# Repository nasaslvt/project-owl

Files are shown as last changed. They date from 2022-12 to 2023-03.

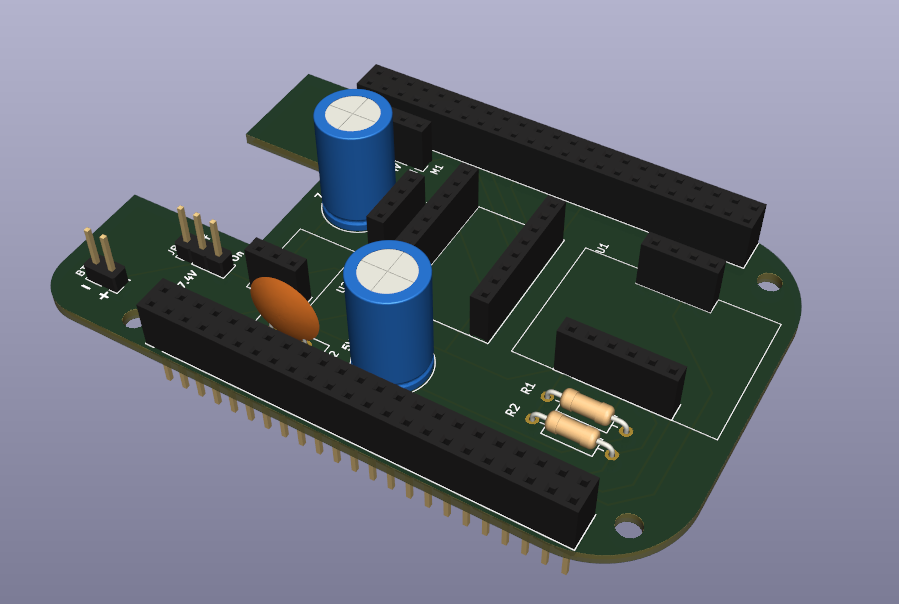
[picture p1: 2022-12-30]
doc/cape_model_v1-4.png

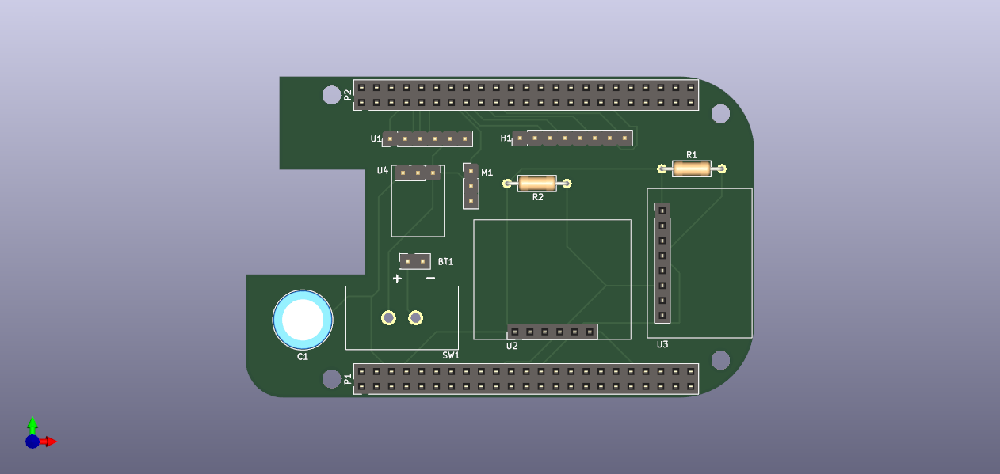
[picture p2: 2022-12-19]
kicad/cape/cape.png

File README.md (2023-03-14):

# project-owl

## Repository Structure
- `beagle`: BeagleBone Black source code
- `conf`: Configuration files, especially for Dire Wolf
- `doc`: Documentation, including block diagrams and schematics
- `esp`: ESP32-CAM source code
- `kicad`: KiCad project files

## Documentation

Schematics were created with KiCad and follow the \<version>.\<subversion> naming convention.  
Block diagrams were created with DigiKey's online [SchemeIt tool](https://www.digikey.com/schemeit/project/project-owl-26cf1e4f4a01456586e33678977ee045).

## Configuration

#### Setup

Install rtl_test, rtl_fm, etc.
```bash
apt-get install rtl-sdr sox
```

Build and install the latest direwolf (1.6 at time of this writing)
```bash
sudo apt-get install git gcc g++ make cmake libasound2-dev libudev-dev
cd ~
mkdir src && cd src
git clone https://www.github.com/wb2osz/direwolf
mkdir build && cd build
cmake ..
make -j4
sudo make install
make install-conf
exit
```

Copy `receive.conf` from this repository to `~/conf/receive.conf`

### ESP32-Camera

#### Flashing

todo

## Operation
### Using rtl_fm
[Reference guide](http://kmkeen.com/rtl-demod-guide/).
To listen to FM radio: `rtl_fm -M wbfm -f 90.7M | sox -r 32k -t raw -e s -b 16 -c 1 -V1 - test.wav`
To use rtl_fm and Dire Wolf: `rtl_fm  -f 145.70M - | direwolf -c receive.conf` or run `receive.sh`.
We are using **145.70 MHz** as our test frequency, although APRS for North America is 144.39M. 

## Debugging
The user running Dire Wolf must be a member of the `audio` group.

## Licensing
The KiCad footprint and model for the L101011MS02Q were provided by SnapEDA under the CC-BY-SA 4.0 license: https://www.snapeda.com/parts/L101011MS02Q/C&K/view-part/?ref=digikey

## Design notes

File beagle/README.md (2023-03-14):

# BeagleBone Black Wireless

The BeagleBone Black Wireless (BBB) is running the [Debian 10.3 2020-04-06 4GB eMMC IoT firmware](https://debian.beagleboard.org/images/bone-eMMC-flasher-debian-10.3-iot-armhf-2020-04-06-4gb.img.xz). This firmware is a Debian Buster IoT (without graphical desktop) image specifically designed for flashing the on-board eMMC memory of the BeagleBone via a microSD card.

The BBB is hosting a wireless access point with the SSID "owl". The network has a DHCP range of 192.168.8.50 to 192.168.8.150 and a listen address of 192.168.8.1. The ESP32-Cam is configured to connect to this network on startup with a static ip address of 192.168.8.10.

## Configuration

#### Flashing Firmware

* Use the Rufus software to flash the [Debian 10.3 2020-04-06 4GB eMMC IoT Flasher image](https://debian.beagleboard.org/images/bone-eMMC-flasher-debian-10.3-iot-armhf-2020-04-06-4gb.img.xz) onto the SD card. 
* Insert the SD card into the BeagleBone and hold down the "User Boot" button (located near the SD card slot). 
* Connect the power source (USB or 5V adaptor) while holding down the "User Boot" button.
* Release the button once the bank of 4 LED's light up for a few seconds.
* The flashing process will take approximately 30-45 minutes. 
* Once the flashing is complete, the bank of 4 LED's to the right of the Ethernet will turn off. 
* Power down the BeagleBone Black, remove the SD card, and power up the BeagleBone Black. 

* To connect to the BeagleBone via USB, use the following command:
```bash
ssh debian@192.168.7.1 or ssh debian@192.168.6.1
```
* When prompted, enter the password `temppwd`.

* Configure users and passwords
```bash
sudo su
passwd
adduser slvt
usermod -aG sudo slvt
```

* Setup Wireless Access Point
```bash
sudo sed -i -e 's:USE_PERSONAL_SSID="BeagleBone":USE_PERSONAL_SSID="owl":g' /etc/default/bb-wl18xx
sudo sed -i -e 's:USE_PERSONAL_PASSWORD="BeagleBone":USE_PERSONAL_PASSWORD="str1g1f0rm35":g' /etc/default/bb-wl18xx
sudo sed -i -e 's:USE_APPENDED_SSID=yes:USE_APPENDED_SSID=no:g' /etc/default/bb-wl18xx
sudo reboot now
```

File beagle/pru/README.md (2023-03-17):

# Programmable Real-Time Unit

## Overview

The BeagleBone has both an ARM processor running Linux and two Programmable Real-Time Units (PRUs). The PRUs have 32-bit cores which run independently of the ARM processor, therefore they can be programmed to respond quickly to inputs and produce very precisely timed outputs. This is necessary for our application, which requires the use of two Parallax Feedback 360° High-Speed Servos. These servos are controlled by a 50 Hz PWM signal, and also have a return signal line from an internal Hall effect sensor system that provides digital angular position feedback at a frequency of 910 Hz. To decode this signal in software, the PRU is used to handle the return signal, reading the data and sending it back to the ARM processor. The ARM processor then uses this data to control the servo, with each PRU reading the feedback signal of an individual servo.

## Configuration

In order to enable the swivel servo feedback pin (P8_15) and rotation servo feedback pin (P8_27) to work with the PRU, the pins must be explicitly configured. To configure P8_15, the command `config-pin P8_15 pruin` must be used. To configure P8_27, the virtual cape for HDMI functionality must first be disabled by uncommenting the `disable_uboot_overlay_video=1` line in `/boot/uEnv.txt` and rebooting. Then the command `config-pin P8_27 pruin` can be used to configure the pin.

## Usage

```
sudo ./start.sh
```

## References
1. [PRU Cookbook](https://beagleboard.org/static/prucookbook/)
2. [Frequency Measurement with PRU BeagleBone CYCLE Register](https://github.com/SuperEjik/frequency-measurement-with-PRU-BeagleBone-CYCLE-register-)
3. [Programming the BeagleBone PRU-ICSS](https://www.glennklockwood.com/embedded/beaglebone-pru.html)
4. [AM335x and AMIC110 Sitara™ Processors Technical Reference Manual](https://www.ti.com/lit/ug/spruh73q/spruh73q.pdf)
5. [BeagleBone Black System Reference Manual 2020](https://kilobaser.com/wp-content/uploads/2021/02/BBB_SRM.pdf)
6. [PRU Debugger](https://github.com/poopgiggle/prudebug)

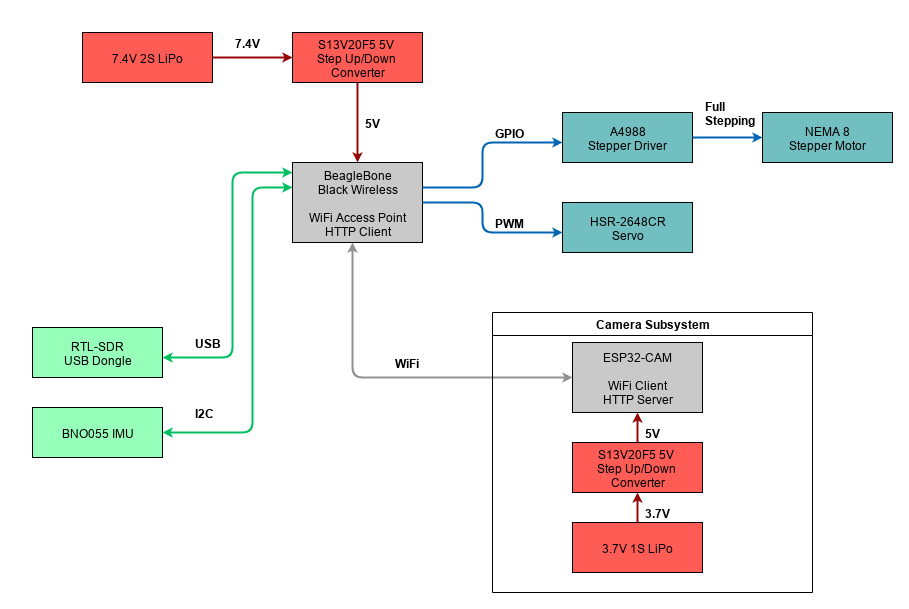
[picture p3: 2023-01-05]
doc/Project-OWL.png

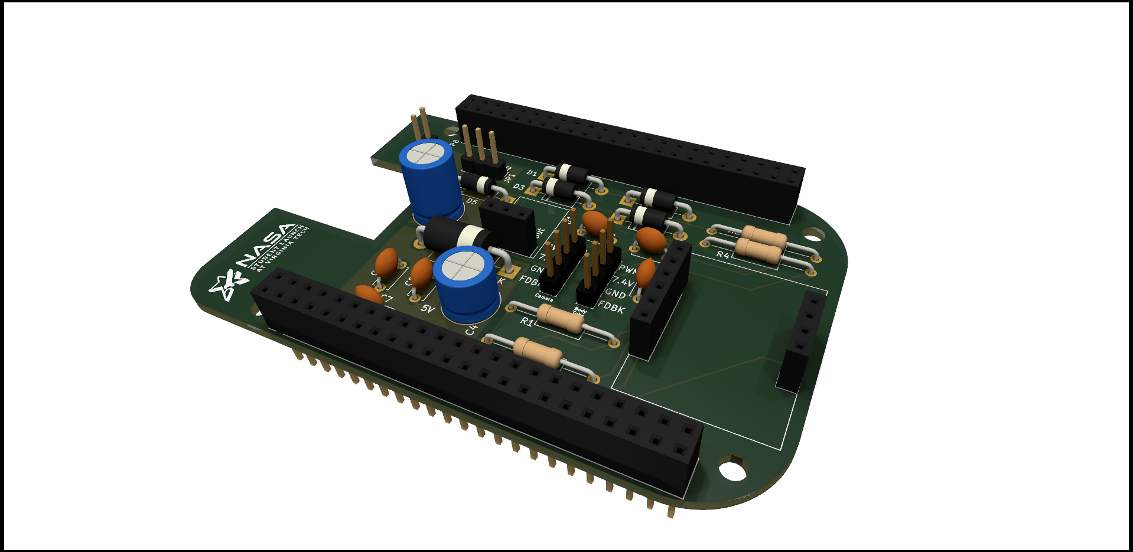
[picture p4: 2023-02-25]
kicad/cape/cape_orthographic.png

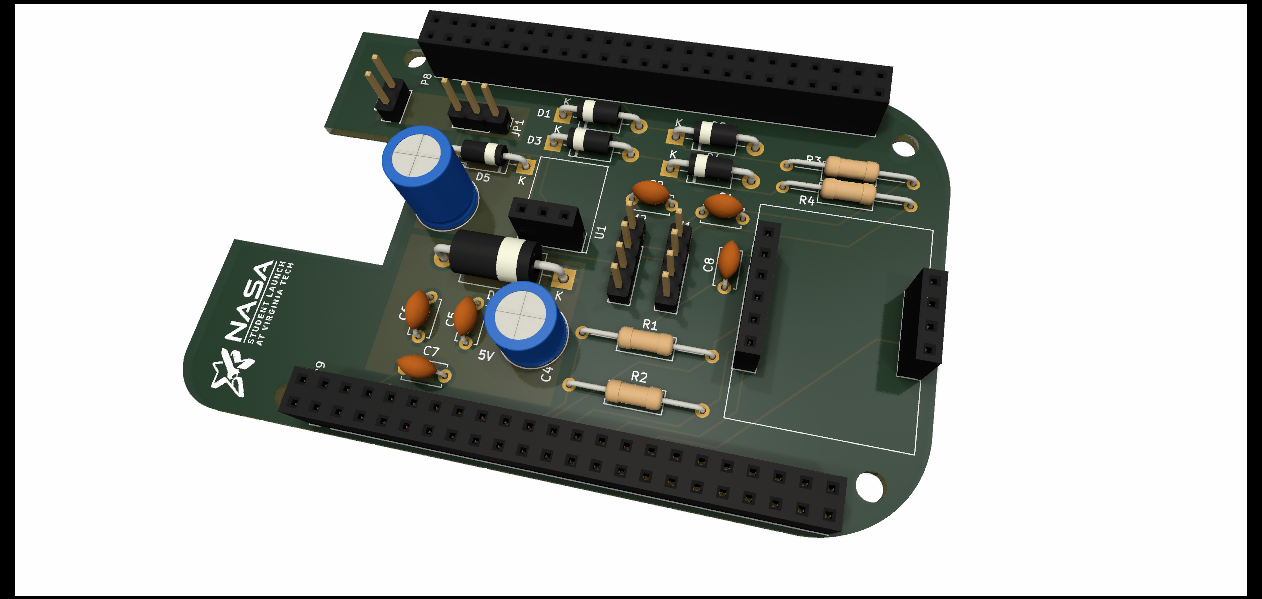
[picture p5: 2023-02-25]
kicad/cape/cape_raytraced.png

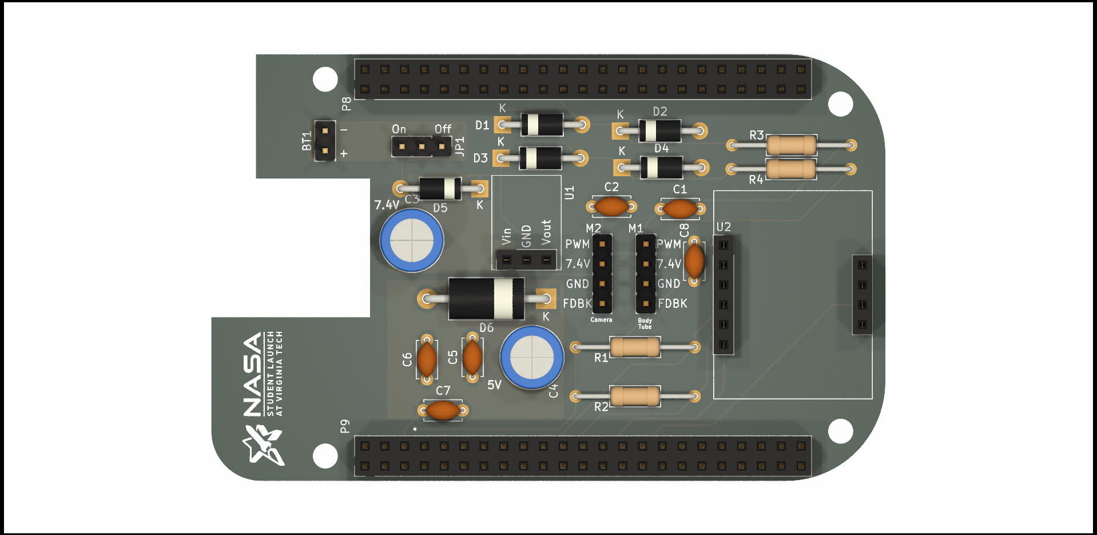
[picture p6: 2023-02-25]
kicad/cape/cape_isometric.png

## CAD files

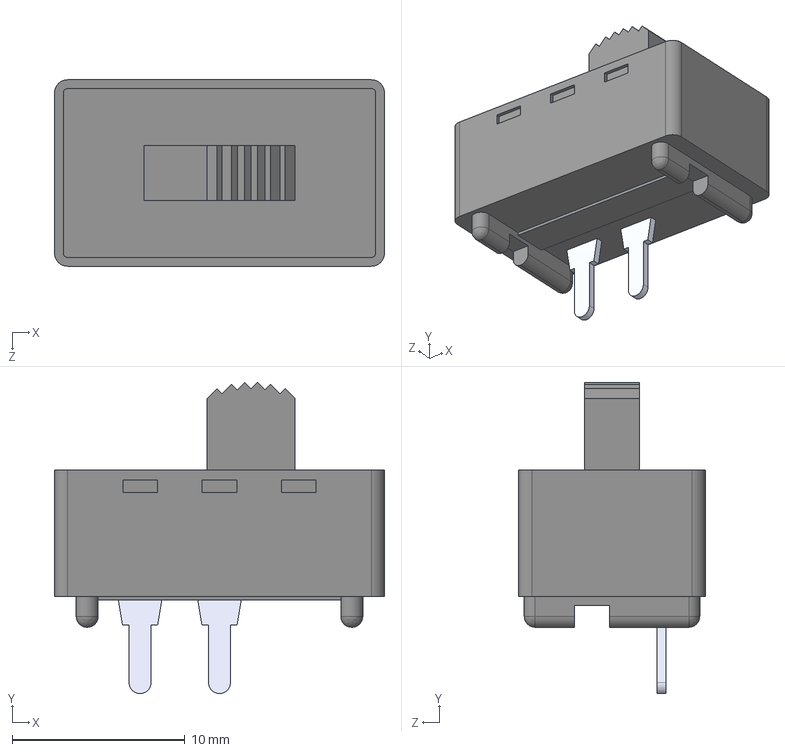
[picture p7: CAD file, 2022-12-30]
kicad/payload_3dmodels/L101011MS02Q.step
19.1 x 18.0 x 10.8 mm

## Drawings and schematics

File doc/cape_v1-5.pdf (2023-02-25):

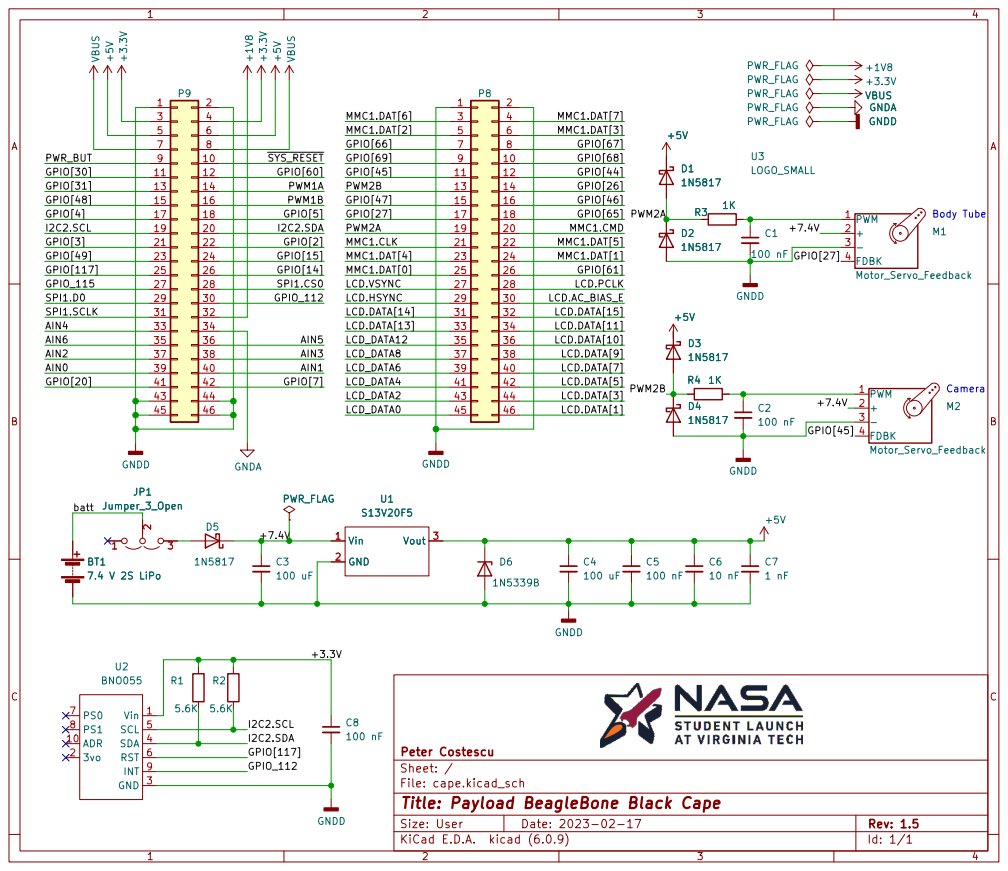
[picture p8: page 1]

LCD.DATA[15] LCD.AC_BIAS_E GPIO[61]
LCD.DATA[10] LCD.PCLK

File: cape.kicad_sch Sheet: / Peter Costescu

Id: 1/1 Title: Payload BeagleBone Black Cape

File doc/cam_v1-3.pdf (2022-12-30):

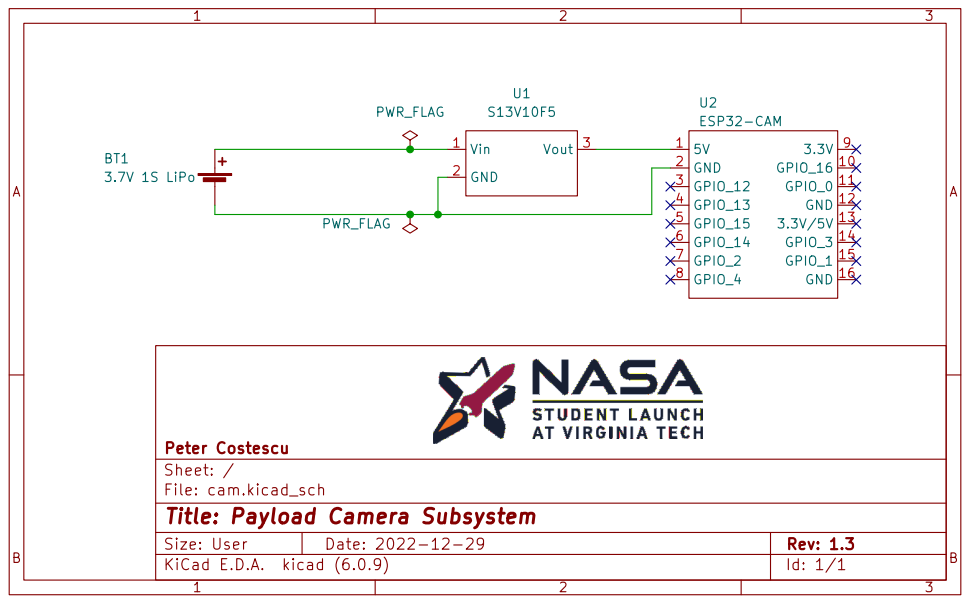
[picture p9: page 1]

File: cam.kicad_sch Sheet: / Peter Costescu

Id: 1/1 Title: Payload Camera Subsystem

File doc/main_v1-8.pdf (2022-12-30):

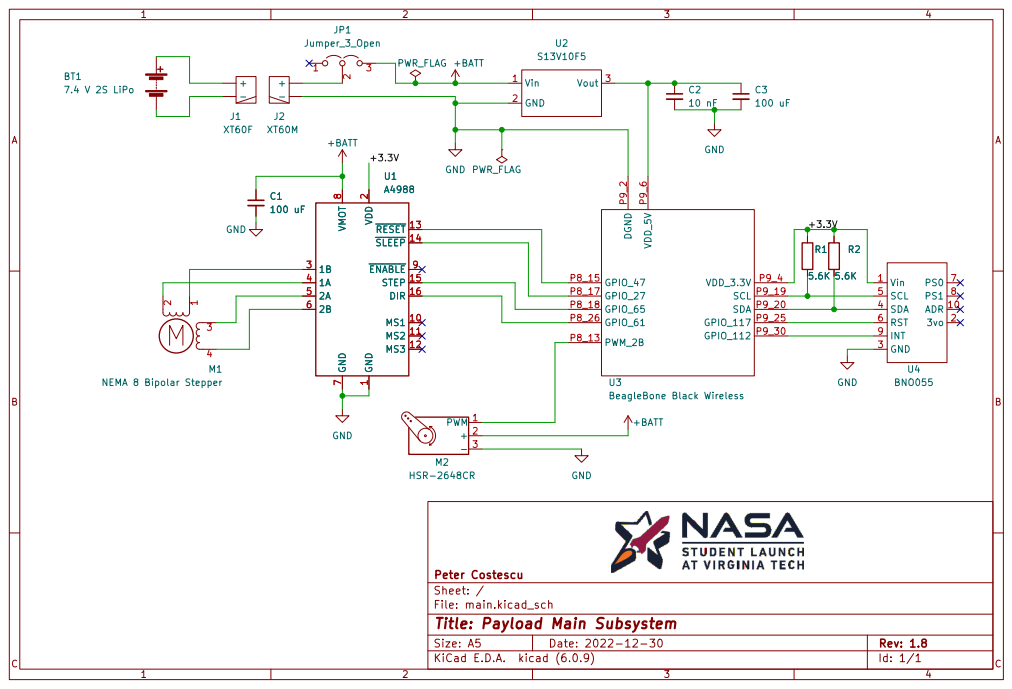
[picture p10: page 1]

1 MS1 10 MS2 11 MS3 12 ~{RESET}13 ~{SLEEP}14 STEP 15 DIR 16 VDD

File: main.kicad_sch Sheet: / Peter Costescu GND

Id: 1/1 Title: Payload Main Subsystem

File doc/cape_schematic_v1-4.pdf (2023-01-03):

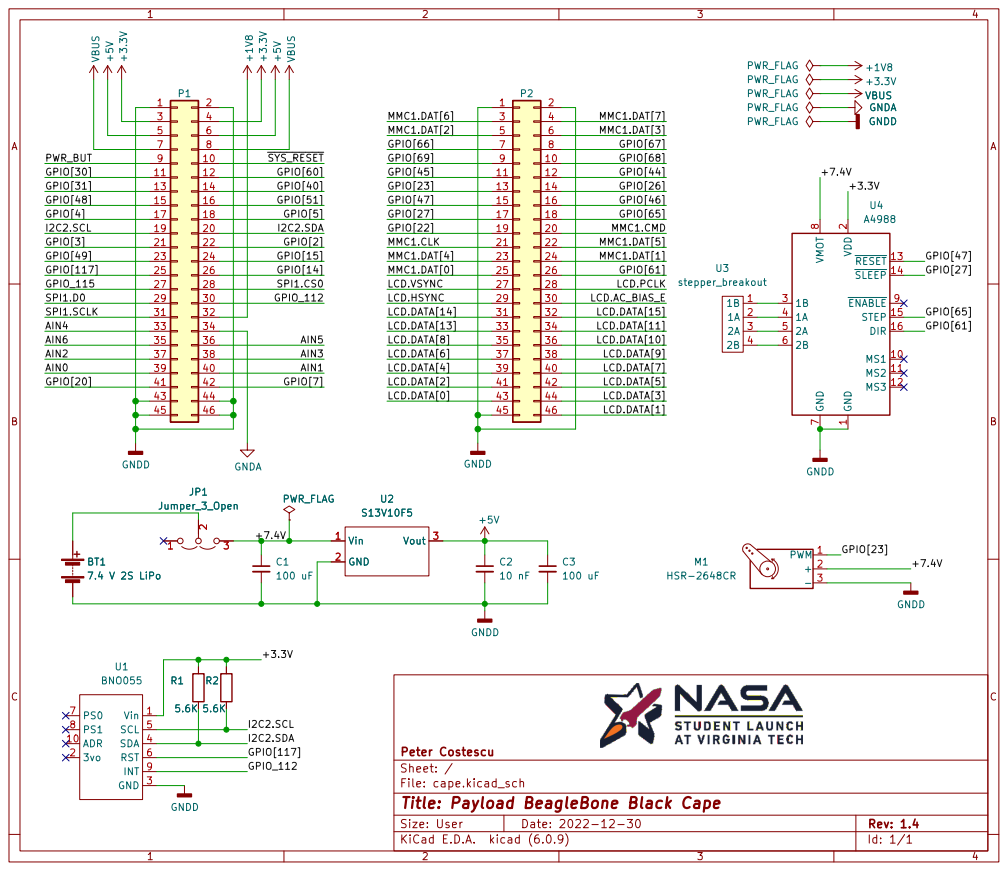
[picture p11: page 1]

1 MS1 10 MS2 11 MS3 12 ~{RESET}13 ~{SLEEP}14 STEP 15 DIR 16 VDD

Id: 1/1 Title: Payload BeagleBone Black Cape

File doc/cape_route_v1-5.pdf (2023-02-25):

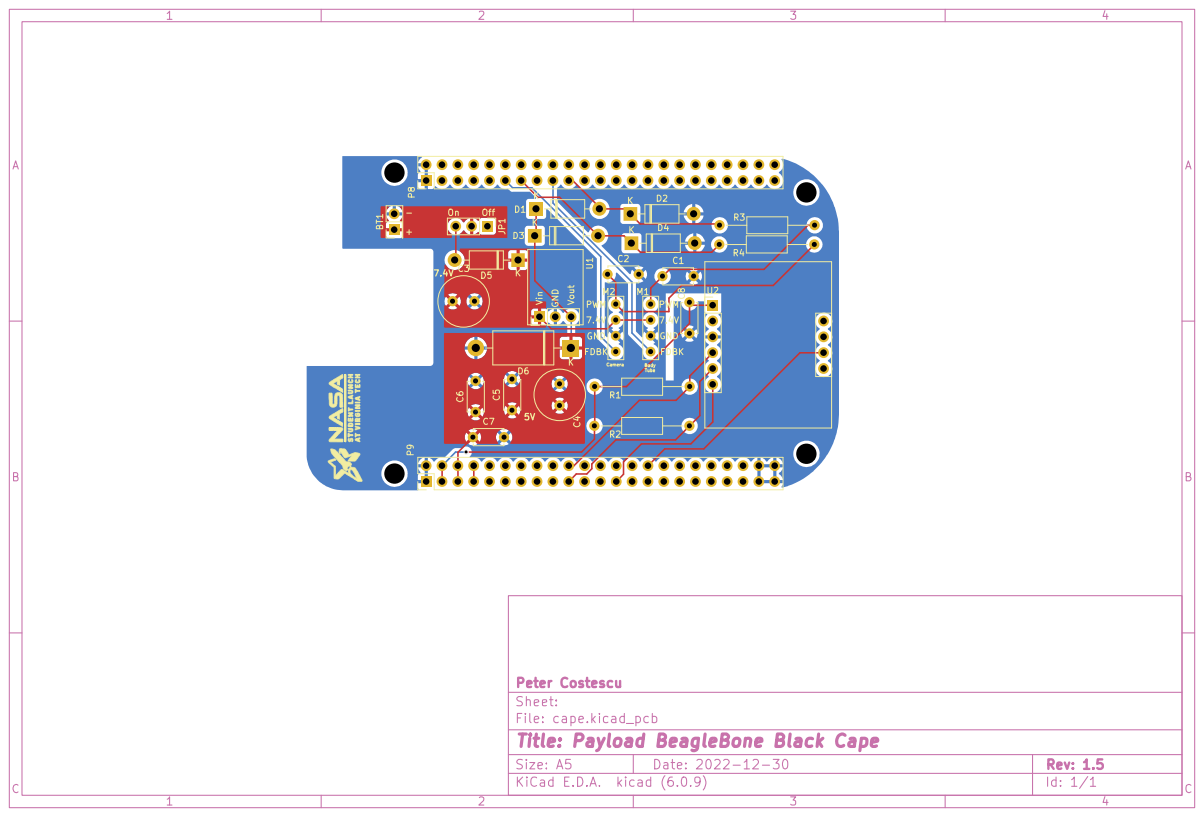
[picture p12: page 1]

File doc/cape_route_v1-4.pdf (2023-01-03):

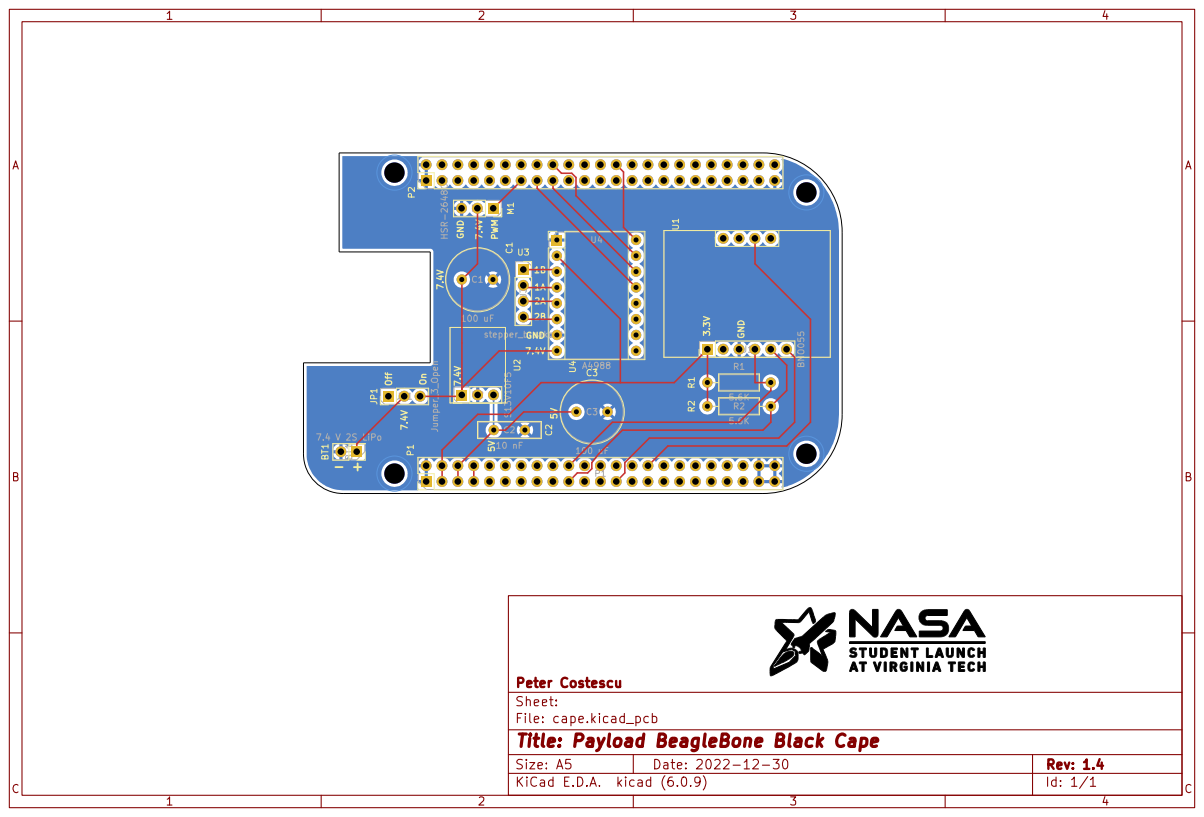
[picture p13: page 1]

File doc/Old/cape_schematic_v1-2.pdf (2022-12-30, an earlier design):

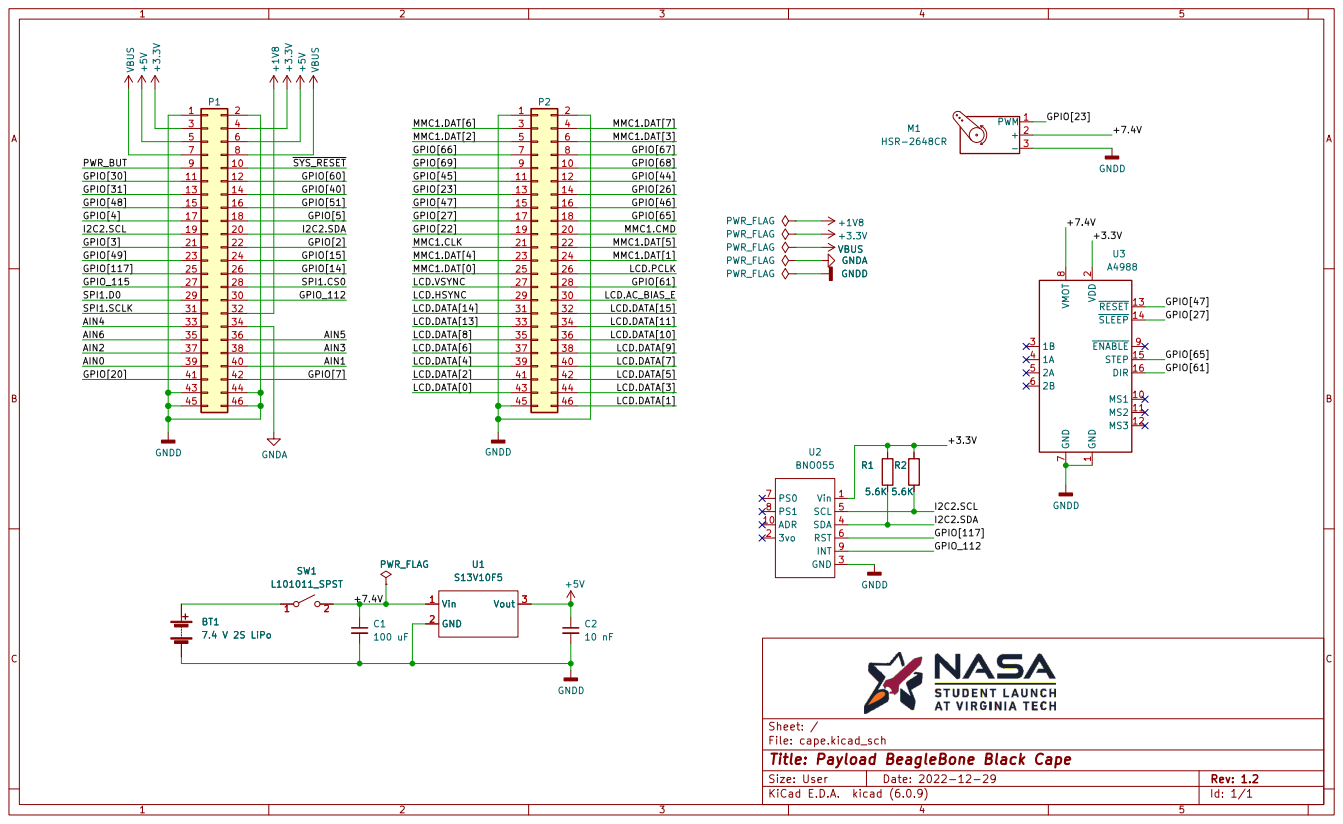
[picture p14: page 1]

LCD.DATA[15] LCD.PCLK
GPIO[61]

1 MS1 10 MS2 11 MS3 12 ~{RESET}13 ~{SLEEP}14 STEP 15 DIR 16 VDD

LCD.DATA[13] LCD.HSYNC
LCD.DATA[14]

File: cape.kicad_sch Sheet: /
Id: 1/1 Title: Payload BeagleBone Black Cape

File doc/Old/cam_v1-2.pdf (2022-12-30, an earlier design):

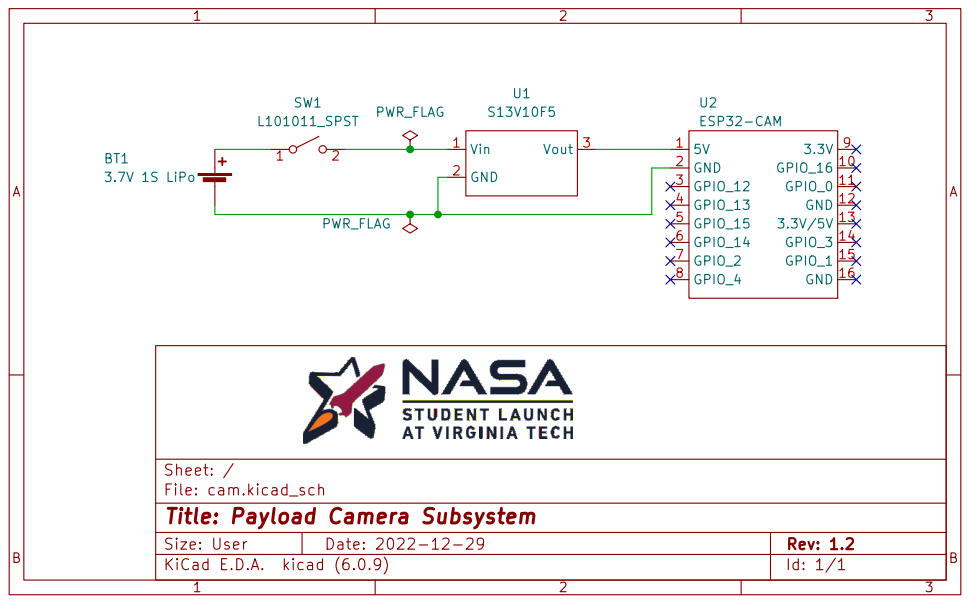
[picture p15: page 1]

Id: 1/1 Title: Payload Camera Subsystem

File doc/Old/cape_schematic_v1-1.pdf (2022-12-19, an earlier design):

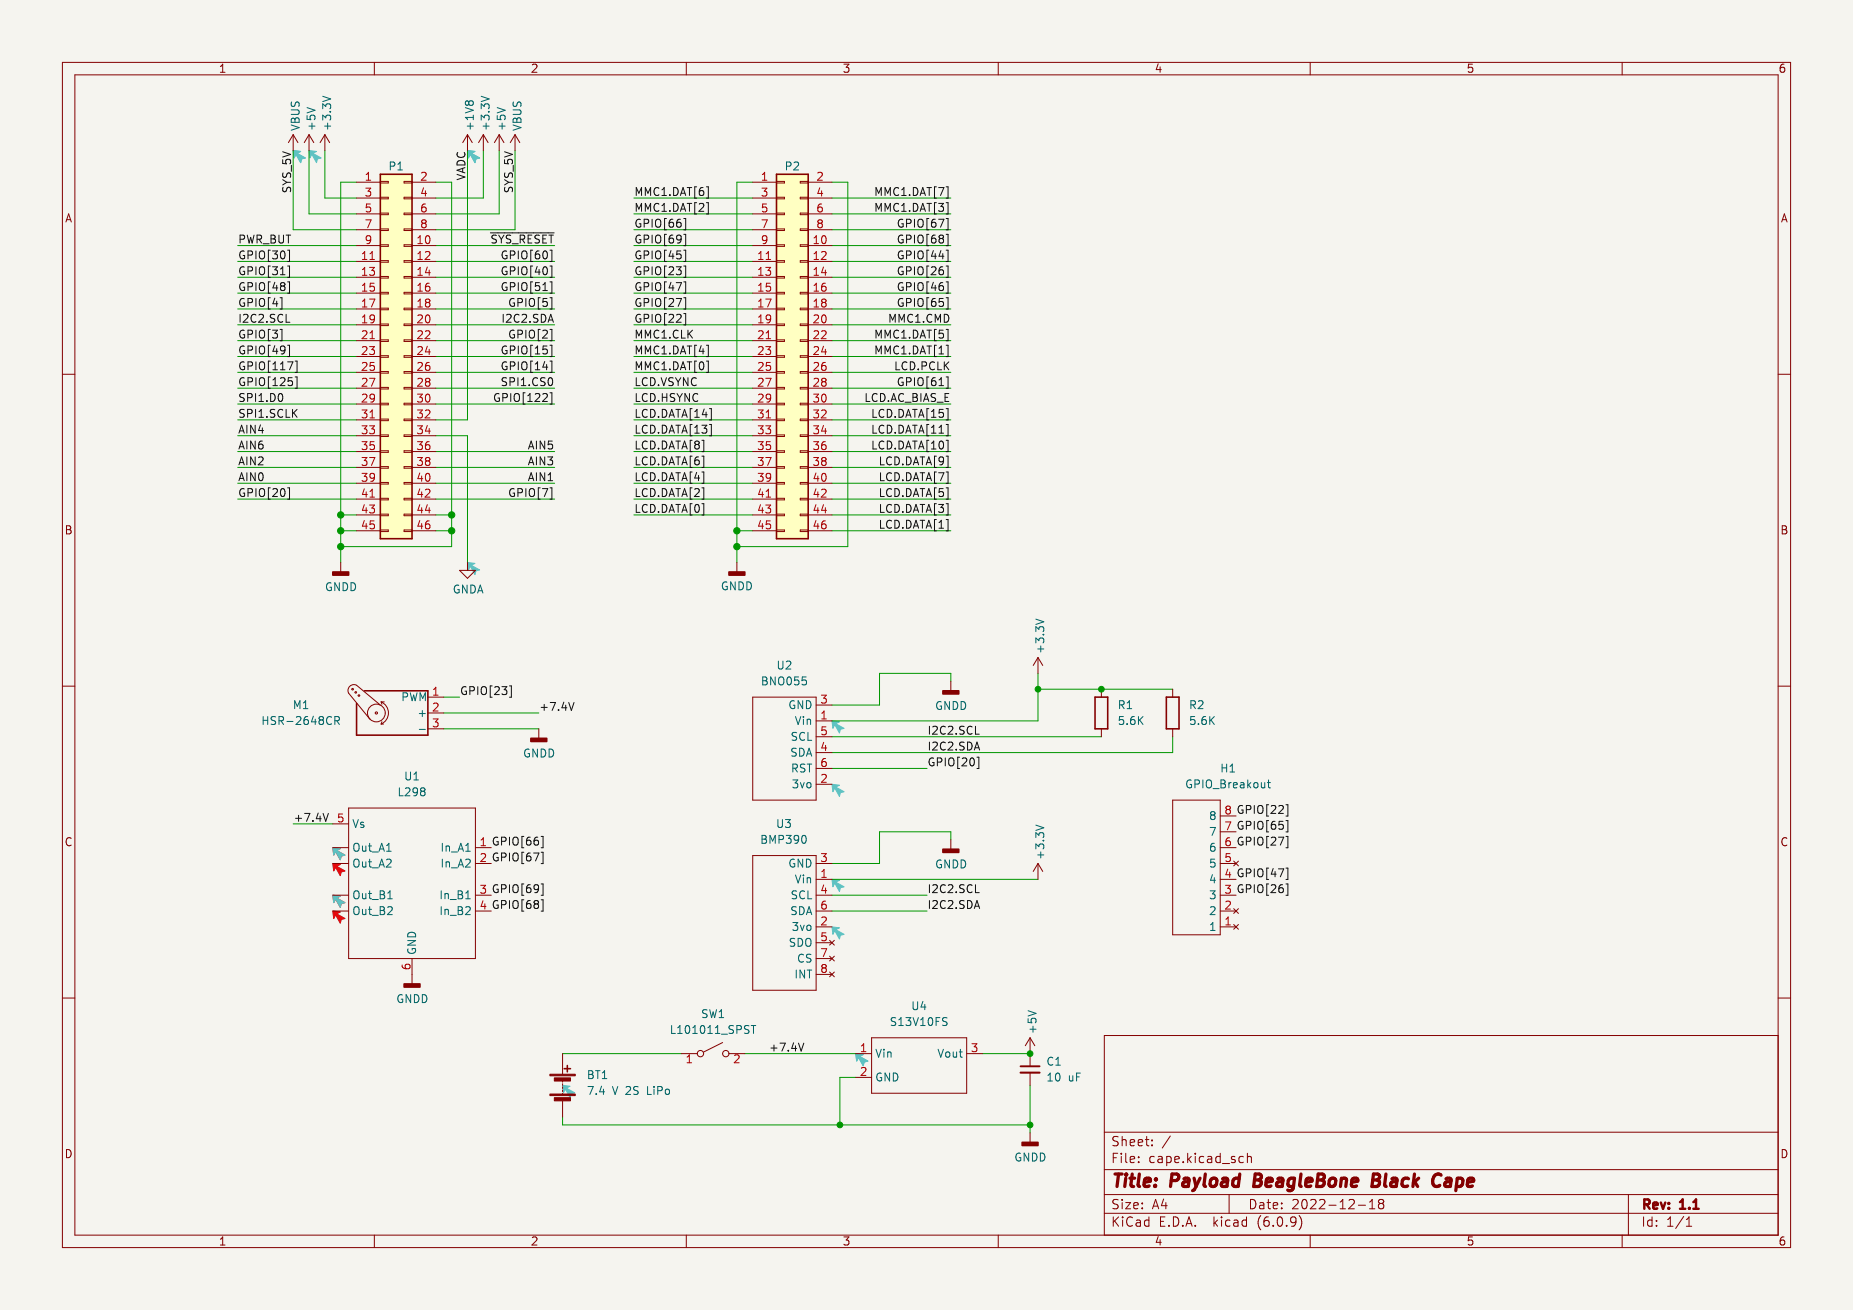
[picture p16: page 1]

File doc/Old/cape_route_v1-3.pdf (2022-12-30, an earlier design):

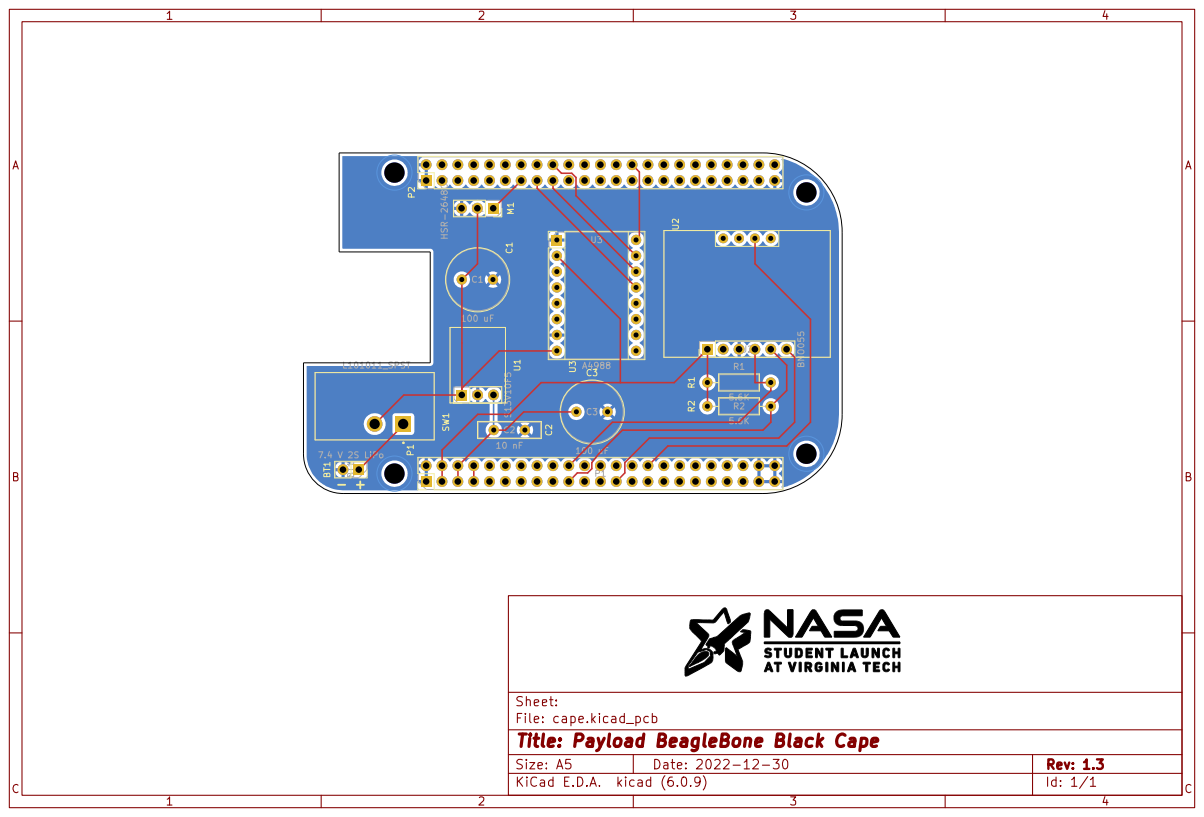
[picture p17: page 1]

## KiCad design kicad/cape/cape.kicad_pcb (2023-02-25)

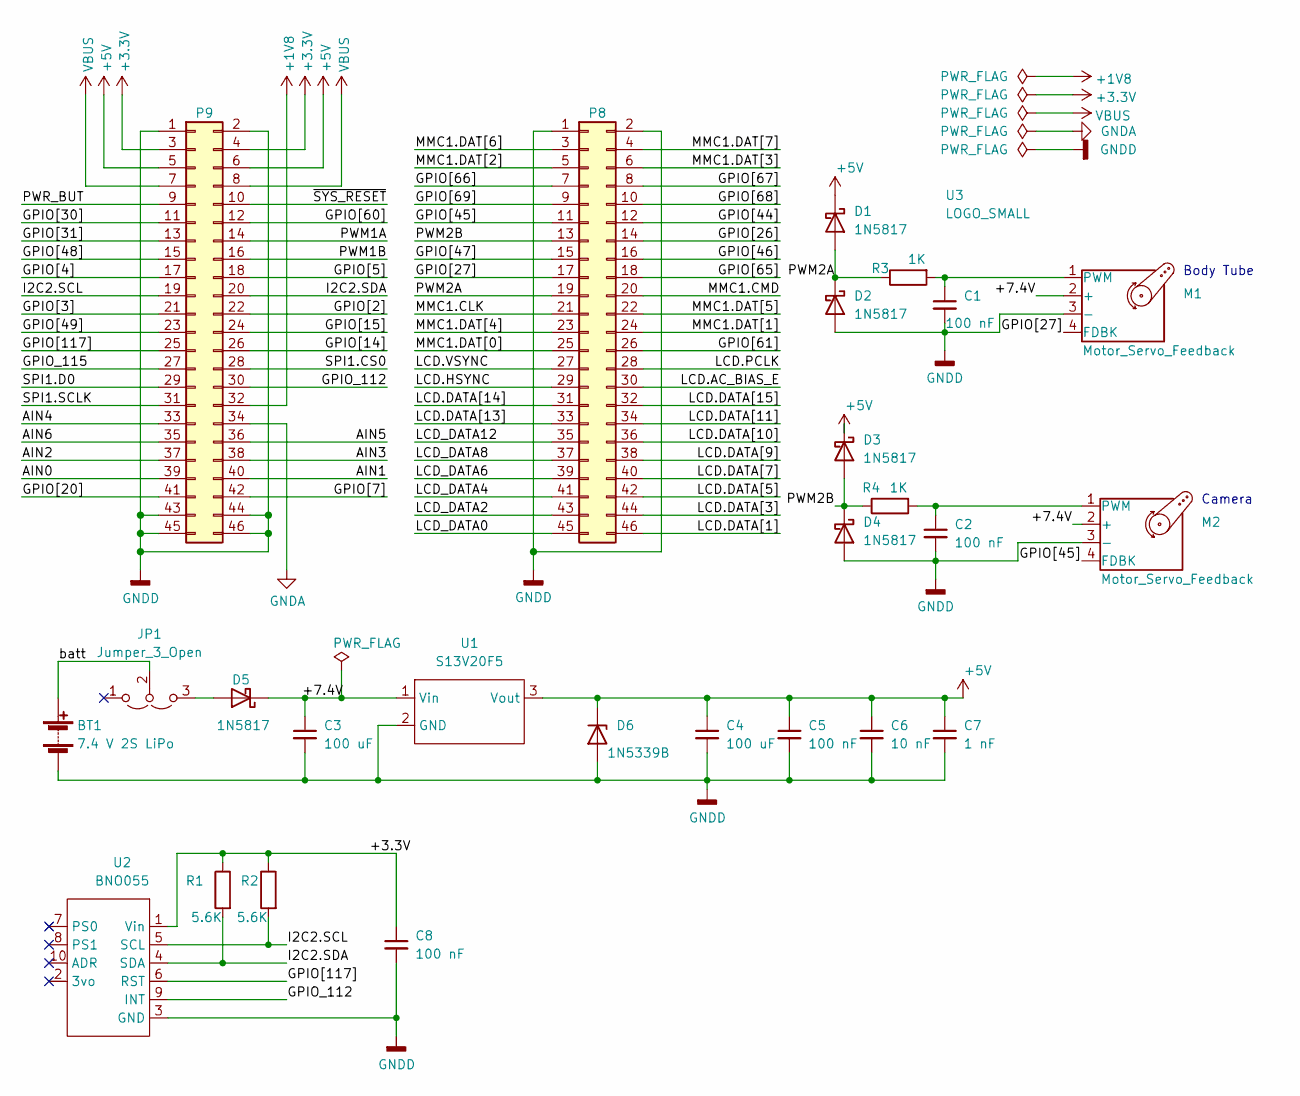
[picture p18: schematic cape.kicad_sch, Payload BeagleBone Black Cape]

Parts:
BT1: 7.4 V 2S LiPo; PinHeader_2x01_P2.54mm_Vertical
C1, C2, C5, C8: 100 nF; C_Disc_D4.7mm_W2.5mm_P5.00mm
C3: 100 uF; C_Radial_D8.0mm_H11.5mm_P3.50mm
C4: 100 uF; C_Radial_D8.0mm_H7.0mm_P3.50mm
C6: 10 nF; C_Disc_D4.7mm_W2.5mm_P5.00mm
C7: 1 nF; C_Disc_D4.7mm_W2.5mm_P5.00mm
D1, D2, D3, D4, D5: 1N5817; D_DO-41_SOD81_P10.16mm_Horizontal
D6: 1N5339B; D_DO-201_P15.24mm_Horizontal
JP1: Jumper_3_Open; PinHeader_1x03_P2.54mm_Vertical
M1, M2: Motor_Servo_Feedback; FeedbackServo
P8, P9: BeagleBone_Black_Header; PinHeader_2x23_P2.54mm_Vertical
R1, R2: 5.6K; R_Axial_DIN0207_L6.3mm_D2.5mm_P15.24mm_Horizontal
R3, R4: 1K; R_Axial_DIN0207_L6.3mm_D2.5mm_P15.24mm_Horizontal
U1: S13V20F5; S13V10F5
U2: BNO055
U3: LOGO_SMALL; logo

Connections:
+1V8: P9.32
+3.3V: C8.1, P9.3, P9.4, R1.1, R2.1, U2.1 (Vin)
+5V: C4.1, C5.1, C6.1, C7.1, D1.1 (K), D3.1 (K), D6.1 (K), P9.5, P9.6, U1.3 (Vout)
/+7.4V: C3.1, D5.1 (K), M1.2 (+), M2.2 (+), U1.1 (Vin)
/AIN0: P9.39
/AIN1: P9.40
/AIN2: P9.37
/AIN3: P9.38
/AIN4: P9.33
/AIN5: P9.36
/AIN6: P9.35
/GPIO[2]: P9.22
/GPIO[3]: P9.21
/GPIO[4]: P9.17
/GPIO[5]: P9.18
/GPIO[7]: P9.42
/GPIO[14]: P9.26
/GPIO[15]: P9.24
/GPIO[20]: P9.41
/GPIO[26]: P8.14
/GPIO[27]: M1.4 (FDBK), P8.17
/GPIO[30]: P9.11
/GPIO[31]: P9.13
/GPIO[44]: P8.12
/GPIO[45]: M2.4 (FDBK), P8.11
/GPIO[46]: P8.16
/GPIO[47]: P8.15
/GPIO[48]: P9.15
/GPIO[49]: P9.23
/GPIO[60]: P9.12
/GPIO[61]: P8.26
/GPIO[65]: P8.18
/GPIO[66]: P8.7
/GPIO[67]: P8.8
/GPIO[68]: P8.10
/GPIO[69]: P8.9
/GPIO[117]: P9.25, U2.6 (RST)
/GPIO_112: P9.30, U2.9 (INT)
/GPIO_115: P9.27
/I2C2.SCL: P9.19, R2.2, U2.5 (SCL)
/I2C2.SDA: P9.20, R1.2, U2.4 (SDA)
/LCD.AC_BIAS_E: P8.30
/LCD.DATA[1]: P8.46
/LCD.DATA[3]: P8.44
/LCD.DATA[5]: P8.42
/LCD.DATA[7]: P8.40
/LCD.DATA[9]: P8.38
/LCD.DATA[10]: P8.36
/LCD.DATA[11]: P8.34
/LCD.DATA[13]: P8.33
/LCD.DATA[14]: P8.31
/LCD.DATA[15]: P8.32
/LCD.HSYNC: P8.29
/LCD.PCLK: P8.28
/LCD.VSYNC: P8.27
/LCD_DATA0: P8.45
/LCD_DATA2: P8.43
/LCD_DATA4: P8.41
/LCD_DATA6: P8.39
/LCD_DATA8: P8.37
/LCD_DATA12: P8.35
/MMC1.CLK: P8.21
/MMC1.CMD: P8.20
/MMC1.DAT[0]: P8.25
/MMC1.DAT[1]: P8.24
/MMC1.DAT[2]: P8.5
/MMC1.DAT[3]: P8.6
/MMC1.DAT[4]: P8.23
/MMC1.DAT[5]: P8.22
/MMC1.DAT[6]: P8.3
/MMC1.DAT[7]: P8.4
/PWM1A: P9.14
/PWM1B: P9.16
/PWM2A: D1.2 (A), D2.1 (K), P8.19, R3.1
/PWM2B: D3.2 (A), D4.1 (K), P8.13, R4.1
/PWR_BUT: P9.9
/SPI1.CS0: P9.28
/SPI1.D0: P9.29
/SPI1.SCLK: P9.31
/batt: BT1.1 (+), JP1.2 (C)
/~SYS_RESET: P9.10
GNDA: P9.34
GNDD: BT1.2 (-), C1.2, C2.2, C3.2, C4.2, C5.2, C6.2, C7.2, C8.2, D2.2 (A), D4.2 (A), D6.2 (A), M1.3 (-), M2.3 (-), P8.1, P8.2, P9.1, P9.2, P9.43, P9.44, P9.45, P9.46, U1.2 (GND), U2.3 (GND)
unnamed: C1.1, M1.1 (PWM), R3.2
unnamed: C2.1, M2.1 (PWM), R4.2
unnamed: D5.2 (A), JP1.3 (B)
VBUS: P9.7, P9.8

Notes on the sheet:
Camera
Body Tube

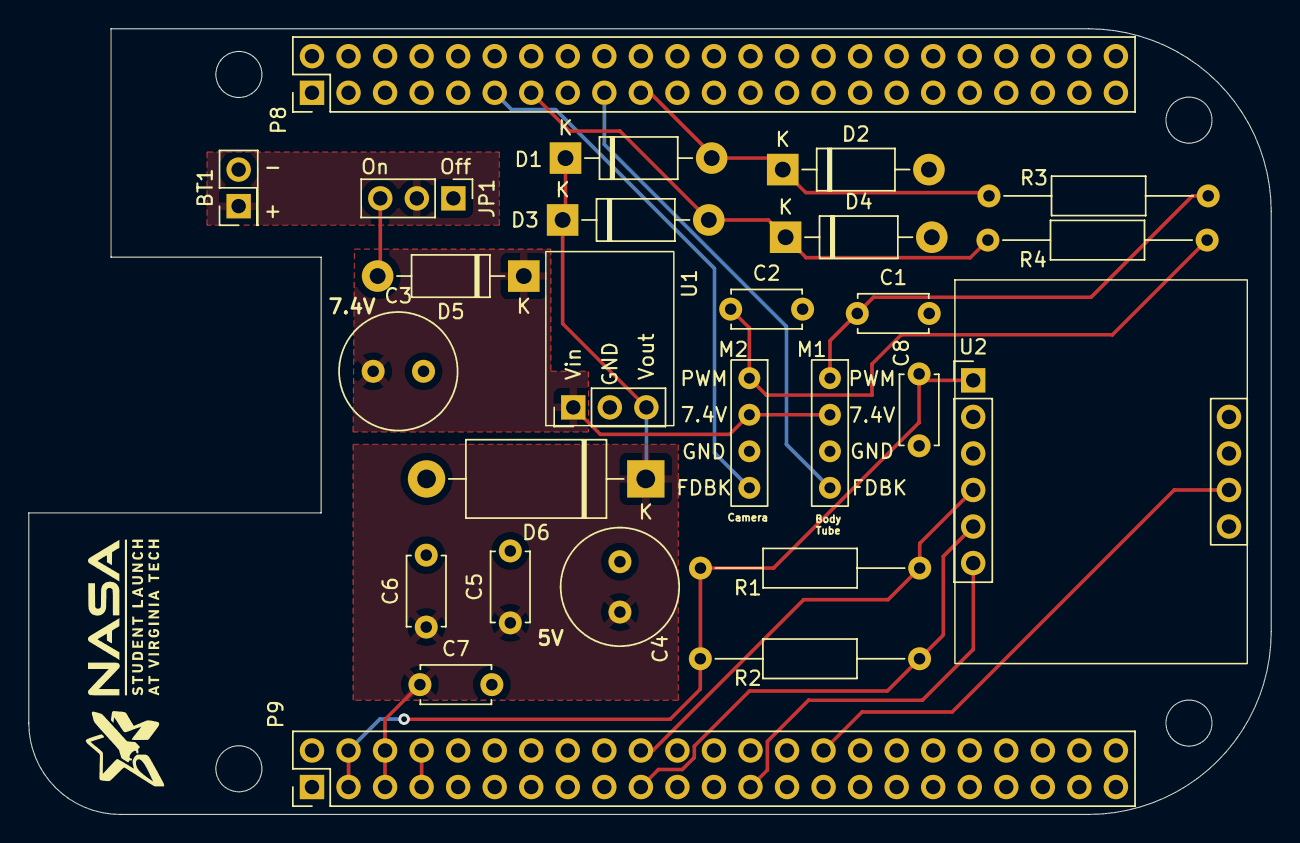
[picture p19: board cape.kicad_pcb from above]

Board: 2 copper layers, 86.4 x 54.6 mm, 31 parts (0 on the bottom side), 17 nets.

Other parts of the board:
MH1, MH2, MH3, MH4: MountingHole_3.2mm_M3_DIN965

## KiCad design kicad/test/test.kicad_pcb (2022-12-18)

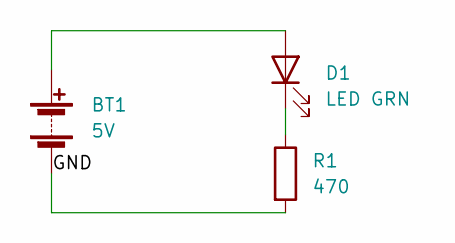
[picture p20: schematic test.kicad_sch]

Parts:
BT1: 5V; PinHeader_2x01_P2.54mm_Vertical
D1: LED GRN; LED_D5.0mm
R1: 470; R_Axial_DIN0309_L9.0mm_D3.2mm_P15.24mm_Horizontal

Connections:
/GND: BT1.2 (-), R1.2
unnamed: BT1.1 (+), D1.2 (A)
unnamed: D1.1 (K), R1.1

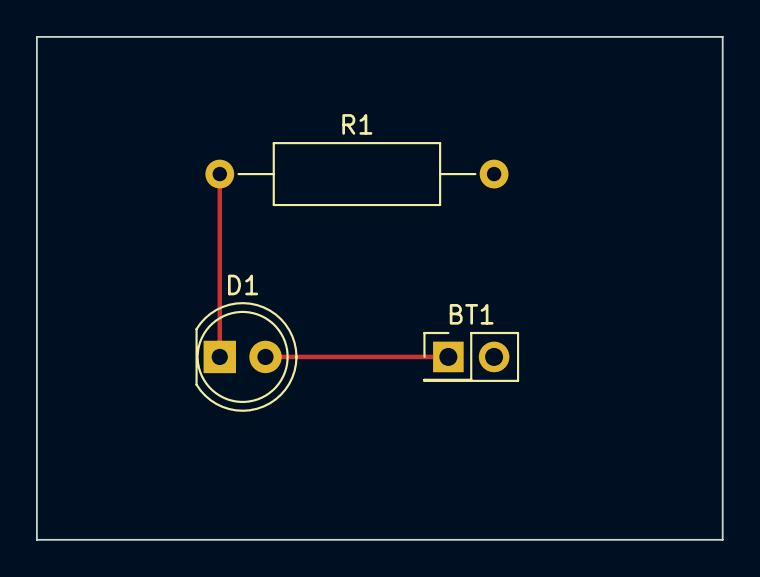
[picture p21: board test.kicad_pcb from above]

Board: 2 copper layers, 38.1 x 27.9 mm, 3 parts (0 on the bottom side), 3 nets.

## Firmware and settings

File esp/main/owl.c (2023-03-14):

#include <esp_wifi.h>
#include <esp_event.h>
#include <esp_log.h>
#include <esp_system.h>
#include <nvs_flash.h>
#include <sys/param.h>
#include "esp_netif.h"
#include <esp_http_server.h>
#include <esp_camera.h>
#include <esp_timer.h>
#include <string.h>
#include <dirent.h>
#include<unistd.h>

#include <driver/sdmmc_host.h>
#include <driver/sdmmc_defs.h>
#include <sdmmc_cmd.h>
#include <esp_vfs_fat.h>

#define WIFI_SSID "owl"
#define WIFI_PASS "str1g1f0rm35"

#define WIFI_STATIC_IP_ADDR "192.168.8.10"
#define WIFI_STATIC_NETMASK_ADDR "255.255.255.0"
#define WIFI_STATIC_GW_ADDR "192.168.8.1"

#define CAM_PIN_PWDN 32
#define CAM_PIN_RESET -1 //software reset will be performed
#define CAM_PIN_XCLK 0
#define CAM_PIN_SIOD 26
#define CAM_PIN_SIOC 27

#define CAM_PIN_D7 35
#define CAM_PIN_D6 34
#define CAM_PIN_D5 39
#define CAM_PIN_D4 36
#define CAM_PIN_D3 21
#define CAM_PIN_D2 19
#define CAM_PIN_D1 18
#define CAM_PIN_D0 5
#define CAM_PIN_VSYNC 25
#define CAM_PIN_HREF 23
#define CAM_PIN_PCLK 22

#define PART_BOUNDARY "123456789000000000000987654321"
static const char* _STREAM_CONTENT_TYPE = "multipart/x-mixed-replace;boundary=" PART_BOUNDARY;
static const char* _STREAM_BOUNDARY = "\r\n--" PART_BOUNDARY "\r\n";
static const char* _STREAM_PART = "Content-Type: image/jpeg\r\nContent-Length: %u\r\n\r\n";

static const char *TAG = "owl";

static camera_config_t camera_config = {
    .pin_pwdn  = CAM_PIN_PWDN,
    .pin_reset = CAM_PIN_RESET,
    .pin_xclk = CAM_PIN_XCLK,
    .pin_sccb_sda = CAM_PIN_SIOD,
    .pin_sccb_scl = CAM_PIN_SIOC,

    .pin_d7 = CAM_PIN_D7,
    .pin_d6 = CAM_PIN_D6,
    .pin_d5 = CAM_PIN_D5,
    .pin_d4 = CAM_PIN_D4,
    .pin_d3 = CAM_PIN_D3,
    .pin_d2 = CAM_PIN_D2,
    .pin_d1 = CAM_PIN_D1,
    .pin_d0 = CAM_PIN_D0,
    .pin_vsync = CAM_PIN_VSYNC,
    .pin_href = CAM_PIN_HREF,
    .pin_pclk = CAM_PIN_PCLK,

    .xclk_freq_hz = 10000000,
    .ledc_timer = LEDC_TIMER_0,
    .ledc_channel = LEDC_CHANNEL_0,

    .pixel_format = PIXFORMAT_JPEG,
    .frame_size = FRAMESIZE_QSXGA,

    .jpeg_quality = 10,
    .fb_count = 2,
    .fb_location = CAMERA_FB_IN_PSRAM,
    .grab_mode = CAMERA_GRAB_LATEST
};

static esp_err_t init_camera() {

    esp_err_t err = esp_camera_init(&camera_config);
    if (err != ESP_OK) {
        ESP_LOGE(TAG, "Camera Init Failed");
        return err;
    }

    sensor_t * s = esp_camera_sensor_get();
    s->set_vflip(s, 1);

    return ESP_OK;
}

static esp_err_t init_sdcard()
{
    sdmmc_host_t host = SDMMC_HOST_DEFAULT();
    sdmmc_slot_config_t slot_config = SDMMC_SLOT_CONFIG_DEFAULT();
    esp_vfs_fat_sdmmc_mount_config_t mount_config = {
        .format_if_mount_failed = false,
        .max_files = 3,
    };
    sdmmc_card_t *card;

    ESP_LOGI(TAG, "Mounting SD card...");
    esp_err_t err = esp_vfs_fat_sdmmc_mount("/sdcard", &host, &slot_config, &mount_config, &card);

    if (err != ESP_OK)
    {
        ESP_LOGE(TAG, "Failed to mount SD card VFAT filesystem. Error: %s", esp_err_to_name(err));
    }

    return ESP_OK;
}

static esp_err_t parse_get(httpd_req_t *req, char **obuf)
{
    char *buf = NULL;
    size_t buf_len = 0;

    buf_len = httpd_req_get_url_query_len(req) + 1;
    if (buf_len > 1) {
        buf = (char *)malloc(buf_len);
        if (!buf) {
            httpd_resp_send_500(req);
            return ESP_FAIL;
        }
        if (httpd_req_get_url_query_str(req, buf, buf_len) == ESP_OK) {
            *obuf = buf;
            return ESP_OK;
        }
        free(buf);
    }
    return ESP_OK;
}
/*
esp_err_t capture_handler(httpd_req_t *req) {

    char *buf = NULL;
    char vflip[1];
    char value[32];

    sensor_t *s = esp_camera_sensor_get();

    if (parse_get(req, &buf) != ESP_OK) {
        return ESP_FAIL;
    }

    httpd_query_key_value(buf, "vflip", vflip, sizeof(vflip));
    httpd_query_key_value(buf, "filter", value, sizeof(value));

    if (vflip[0] == '1') {
        s->set_vflip(s, 0);
    } else {
        s->set_vflip(s, 1);
    }

    s->set_special_effect(s, 0);
    if (strcmp(value, "grayscale")) {
        s->set_special_effect(s, 2);
    }
    if (strcmp(value, "edge")) {
        s->set_special_effect(s, 6);
    }

    free(buf);

    ESP_LOGI(TAG, "Taking picture...");

    camera_fb_t * fb = NULL;
    esp_err_t res = ESP_OK;
    int64_t fr_start = esp_timer_get_time();

    fb = esp_camera_fb_get();
    if (!fb) {
        ESP_LOGE(TAG, "Camera capture failed");
        httpd_resp_send_500(req);
        return ESP_FAIL;
    }

    char *pic_name = malloc(17 + sizeof(int64_t));
    sprintf(pic_name, "/sdcard/pic_%lli.jpg", fr_start);

    FILE *file = fopen(pic_name, "w");
    if (file != NULL)
    {
        ESP_LOGI(TAG, "Fwrite %d", fwrite(fb->buf, 1, fb->len, file));
        ESP_LOGI(TAG, "File saved");
    }
    else
    {
        ESP_LOGE(TAG, "Could not open file =(");
        httpd_resp_send_500(req);
        res = ESP_FAIL;
    }
    fclose(file);
    free(pic_name);

    ESP_LOGI(TAG, "Picture taken! Its size was: %zu bytes", fb->len);
    esp_camera_fb_return(fb);

    int64_t fr_end = esp_timer_get_time();
    ESP_LOGI(TAG, "JPG: %zuKB %ums", fb->len, (uint32_t)((fr_end - fr_start)/1000));
    
    const char resp[] = "Picture Saved";
    httpd_resp_send(req, resp, HTTPD_RESP_USE_STRLEN);

    s->set_vflip(s, 1);
    s->set_special_effect(s, 0);

    return res;
}

esp_err_t file_handler(httpd_req_t *req) {

    char *buf = NULL;
    char value[32];

    if (parse_get(req, &buf) != ESP_OK) {
        return ESP_FAIL;
    }

    esp_err_t err = httpd_query_key_value(buf, "fname", value, sizeof(value));

    free(buf);

    if (err == ESP_ERR_NOT_FOUND) {
        return ESP_OK;
    }

    char *pic_name = malloc(13 + sizeof(value));
    sprintf(pic_name, "/sdcard/%s.jpg", value);

    FILE *file = fopen(pic_name, "r");
    if (file != NULL)
    {
        ESP_LOGI(TAG, "File opened");
    }
    else
    {
        ESP_LOGE(TAG, "Could not open file %s", pic_name);
        httpd_resp_send_500(req);
        return ESP_FAIL;
    }

    fseek(file, 0, SEEK_END);
    int size = ftell(file);
    fseek(file, 0, SEEK_SET);

    char *buffer = malloc(size);
    fread(buffer, 1, size, file);
    fclose(file);
    free(pic_name);

    httpd_resp_set_type(req, "image/jpeg");
    httpd_resp_send(req, buffer, size);
    free(buffer);

    return ESP_OK;
}

esp_err_t list_handler(httpd_req_t *req) {

    char *buf = NULL;
    char value[32];

    if (parse_get(req, &buf) != ESP_OK) {
        return ESP_FAIL;
    }

    esp_err_t err = httpd_query_key_value(buf, "action", value, sizeof(value));

    free(buf);

    if (err == ESP_ERR_NOT_FOUND) {
        return ESP_OK;
    }

    if (strcmp(value, "list") == 0) {
        DIR *dir;
        struct dirent *ent;
        char *html_buffer = malloc(1024);
        char *html_buffer_ptr = html_buffer;

        if ((dir = opendir("/sdcard")) != NULL) {
            while ((ent = readdir(dir)) != NULL) {
                if (ent->d_type == DT_REG) {
                    html_buffer_ptr += sprintf(html_buffer_ptr, "<p>%s</p>", ent->d_name);
                }
            }
            closedir(dir);
        }

        httpd_resp_set_type(req, "text/html");
        httpd_resp_send(req, html_buffer, strlen(html_buffer));
        free(html_buffer);
    }
    else if (strcmp(value, "delete") == 0) {
        char *file_name = malloc(32);
        err = httpd_query_key_value(buf, "fname", file_name, 32);
        if (err == ESP_OK) {
            char *file_path = malloc(13 + strlen(file_name));
            sprintf(file_path, "/sdcard/%s.jpg", file_name);
            if (remove(file_path) == 0) {
                httpd_resp_sendstr(req, "File deleted successfully");
            }
            else {
                httpd_resp_send_500(req);
            }
            free(file_path);
        }
        else {
            httpd_resp_send_500(req);
        }
        free(file_name);
    }
    else {
        httpd_resp_send_500(req);
    }

    return ESP_OK;
}
*/

esp_err_t camera_get_handler(httpd_req_t *req) {
    
    sensor_t * s = esp_camera_sensor_get();
    camera_sensor_info_t * info = esp_camera_sensor_get_info(&s->id);

    char json_response[256];
    sprintf(json_response, "{\n\t\"name\": \"%s\"\n}", info->name);

    httpd_resp_send(req, json_response, strlen(json_response));
    return ESP_OK;
}

static const httpd_uri_t camera_get_uri = {
    .uri       = "/",
    .method    = HTTP_GET,
    .handler   = camera_get_handler,
    .user_ctx  = NULL
};

esp_err_t camera_stream_get_handler(httpd_req_t *req)
{
    sensor_t * s = esp_camera_sensor_get();
    s->set_framesize(s, FRAMESIZE_HD);

    camera_fb_t * fb = NULL;
    esp_err_t res = ESP_OK;
    size_t _jpg_buf_len;
    uint8_t * _jpg_buf;
    char * part_buf[64];
    static int64_t last_frame = 0;
    if(!last_frame) {
        last_frame = esp_timer_get_time();
    }

    res = httpd_resp_set_type(req, _STREAM_CONTENT_TYPE);
    if(res != ESP_OK){
        return res;
    }

    while(true){
        fb = esp_camera_fb_get();
        if (!fb) {
            ESP_LOGE(TAG, "Camera capture failed");
            res = ESP_FAIL;
            break;
        }
        if(fb->format != PIXFORMAT_JPEG){
            bool jpeg_converted = frame2jpg(fb, 80, &_jpg_buf, &_jpg_buf_len);
            if(!jpeg_converted){
                ESP_LOGE(TAG, "JPEG compression failed");
                esp_camera_fb_return(fb);
                res = ESP_FAIL;
            }
        } else {
            _jpg_buf_len = fb->len;
            _jpg_buf = fb->buf;
        }

        if(res == ESP_OK){
            res = httpd_resp_send_chunk(req, _STREAM_BOUNDARY, strlen(_STREAM_BOUNDARY));
        }
        if(res == ESP_OK){
            size_t hlen = snprintf((char *)part_buf, 64, _STREAM_PART, _jpg_buf_len);

            res = httpd_resp_send_chunk(req, (const char *)part_buf, hlen);
        }
        if(res == ESP_OK){
            res = httpd_resp_send_chunk(req, (const char *)_jpg_buf, _jpg_buf_len);
        }
        if(fb->format != PIXFORMAT_JPEG){
            free(_jpg_buf);
        }
        esp_camera_fb_return(fb);
        if(res != ESP_OK){
            break;
        }
        int64_t fr_end = esp_timer_get_time();
        int64_t frame_time = fr_end - last_frame;
        last_frame = fr_end;
        frame_time /= 1000;
        ESP_LOGI(TAG, "MJPG: %uKB %ums (%.1ffps)",
            (uint32_t)(_jpg_buf_len/1024),
            (uint32_t)frame_time, 1000.0 / (uint32_t)frame_time);
    }

    last_frame = 0;
    return res;
}

static const httpd_uri_t camera_stream_get_uri = {
    .uri       = "/stream",
    .method    = HTTP_GET,
    .handler   = camera_stream_get_handler,
    .user_ctx  = NULL
};

esp_err_t camera_record_get_handler(httpd_req_t *req)
{
    sensor_t * s = esp_camera_sensor_get();
    s->set_framesize(s, FRAMESIZE_SVGA);

    camera_fb_t * fb = NULL;
    esp_err_t res = ESP_OK;
    int64_t fr_start;

    char *vid_name = malloc(17 + sizeof(int64_t));
    sprintf(vid_name, "/sdcard/vid_%lli.jpg", esp_timer_get_time());
    FILE *file = fopen(vid_name, "w");

    while(true) {
        fb = esp_camera_fb_get();
        if (fb) {
            fr_start = esp_timer_get_time();
            fwrite(fb->buf, 1, fb->len, file);
            esp_camera_fb_return(fb);
            ESP_LOGI(TAG, "JPG: %zuKB %ums", fb->len/1024, (uint32_t)((esp_timer_get_time() - fr_start)/1000));
        }
    }
    free(vid_name);
    fclose(file);
}

static const httpd_uri_t camera_record_get_uri = {
    .uri       = "/record",
    .method    = HTTP_GET,
    .handler   = camera_record_get_handler,
    .user_ctx  = NULL
};


static httpd_handle_t start_webserver(void)
{
    httpd_handle_t server = NULL;
    httpd_config_t config = HTTPD_DEFAULT_CONFIG();
    config.server_port = 8080;

    // Start the httpd server
    ESP_LOGI(TAG, "Starting server on port: '%d'", config.server_port);
    esp_err_t res = httpd_start(&server, &config);
    if (res == ESP_OK) {
        // Set URI handlers
        ESP_LOGI(TAG, "Registering URI handlers");
        httpd_register_uri_handler(server, &camera_get_uri);
        httpd_register_uri_handler(server, &camera_record_get_uri);
        httpd_register_uri_handler(server, &camera_stream_get_uri);
        return server;
    }
    ESP_LOGI(TAG, "Error starting server: %s", esp_err_to_name(res));
    return NULL;
}

static esp_err_t stop_webserver(httpd_handle_t server)
{
    // Stop the httpd server
    return httpd_stop(server);
}

static void disconnect_handler(void* arg, esp_event_base_t event_base,
                               int32_t event_id, void* event_data)
{
    httpd_handle_t* server = (httpd_handle_t*) arg;
    if (*server) {
        ESP_LOGI(TAG, "Stopping webserver");
        if (stop_webserver(*server) == ESP_OK) {
            *server = NULL;
        } else {
            ESP_LOGE(TAG, "Failed to stop http server");
        }
    }
}

static void connect_handler(void* arg, esp_event_base_t event_base,
                            int32_t event_id, void* event_data)
{
    httpd_handle_t* server = (httpd_handle_t*) arg;
    if (*server == NULL) {
        ESP_LOGI(TAG, "Starting webserver");
        *server = start_webserver();
    }
}

static void set_static_ip(esp_netif_t *netif)
{
    if (esp_netif_dhcpc_stop(netif) != ESP_OK) {
        ESP_LOGE(TAG, "Failed to stop dhcp client");
        return;
    }
    esp_netif_ip_info_t ip;
    memset(&ip, 0 , sizeof(esp_netif_ip_info_t));
    ip.ip.addr = ipaddr_addr(WIFI_STATIC_IP_ADDR);
    ip.netmask.addr = ipaddr_addr(WIFI_STATIC_NETMASK_ADDR);
    ip.gw.addr = ipaddr_addr(WIFI_STATIC_GW_ADDR);
    if (esp_netif_set_ip_info(netif, &ip) != ESP_OK) {
        ESP_LOGE(TAG, "Failed to set ip info");
        return;
    }
    ESP_LOGD(TAG, "Success to set static ip: %s, netmask: %s, gw: %s", WIFI_STATIC_IP_ADDR, WIFI_STATIC_NETMASK_ADDR, WIFI_STATIC_GW_ADDR);
}

static void wifi_event_handler(void* arg, esp_event_base_t event_base,
                                int32_t event_id, void* event_data)
{
    if (event_base == WIFI_EVENT) {
        if (event_id == WIFI_EVENT_STA_START) {
            esp_err_t err = esp_wifi_connect();
            ESP_LOGI(TAG, "esp_wifi_connect: %s", esp_err_to_name(err));
        }
        else if (event_id == WIFI_EVENT_STA_CONNECTED) {
            set_static_ip(arg);
        }
        else if (event_id == WIFI_EVENT_STA_DISCONNECTED) {
            esp_err_t err = esp_wifi_connect();
            ESP_LOGI(TAG, "esp_wifi_connect: %s", esp_err_to_name(err));
            ESP_LOGI(TAG, "retry to connect to the AP");
        }
    }
    else if (event_base == IP_EVENT && event_id == IP_EVENT_STA_GOT_IP) {
        ip_event_got_ip_t* event = (ip_event_got_ip_t*) event_data;
        ESP_LOGI(TAG, "got ip:" IPSTR, IP2STR(&event->ip_info.ip));
    }
}

static void init_wifi() {

    esp_netif_t *sta_netif = esp_netif_create_default_wifi_sta();
    assert(sta_netif);

    wifi_init_config_t cfg = WIFI_INIT_CONFIG_DEFAULT();
    ESP_ERROR_CHECK(esp_wifi_init(&cfg));

    esp_event_handler_instance_t instance_any_id;
    esp_event_handler_instance_t instance_got_ip;
    ESP_ERROR_CHECK(esp_event_handler_instance_register(WIFI_EVENT,
                                                        ESP_EVENT_ANY_ID,
                                                        &wifi_event_handler,
                                                        sta_netif,
                                                        &instance_any_id));
    ESP_ERROR_CHECK(esp_event_handler_instance_register(IP_EVENT,
                                                        IP_EVENT_STA_GOT_IP,
                                                        &wifi_event_handler,
                                                        sta_netif,
                                                        &instance_got_ip));

    wifi_config_t wifi_config = {
        .sta = {
            .ssid = WIFI_SSID,
            .password = WIFI_PASS,
          //.threshold.authmode = WIFI_AUTH_WEP,
        },
    };
    ESP_LOGI(TAG, "Connecting to: %s", WIFI_SSID);
    ESP_ERROR_CHECK(esp_wifi_set_mode(WIFI_MODE_STA));
    ESP_ERROR_CHECK(esp_wifi_set_config(WIFI_IF_STA, &wifi_config));
    ESP_ERROR_CHECK(esp_wifi_start());

    ESP_LOGI(TAG, "init_wifi finished.");
}

void app_main(void)
{
    //Initialize NVS
    esp_err_t ret = nvs_flash_init();
    if (ret == ESP_ERR_NVS_NO_FREE_PAGES || ret == ESP_ERR_NVS_NEW_VERSION_FOUND) {
        ESP_ERROR_CHECK(nvs_flash_erase());
        ret = nvs_flash_init();
    }
    ESP_ERROR_CHECK(ret);

    //Initialize the underlying TCP/IP stack
    ESP_ERROR_CHECK(esp_netif_init());

    //Create default event loop
    ESP_ERROR_CHECK(esp_event_loop_create_default());

    init_wifi();
    init_sdcard();
    init_camera();

    static httpd_handle_t server;

    ESP_ERROR_CHECK(esp_event_handler_register(IP_EVENT, IP_EVENT_STA_GOT_IP, &connect_handler, &server));
    ESP_ERROR_CHECK(esp_event_handler_register(WIFI_EVENT, WIFI_EVENT_STA_DISCONNECTED, &disconnect_handler, &server));

    /* Start the server for the first time */
    server = start_webserver();
}

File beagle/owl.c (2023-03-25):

#include <stdio.h>
#include <stdlib.h>
#include <string.h>
#include <fcntl.h>
#include <unistd.h>
#include <math.h>
#include <time.h>
#include <sys/ioctl.h>
#include <linux/i2c-dev.h>

#include "tcp.h"
#include "servo.h"
#include "imu/bno_support.h"

#define KISSPORT 8001
#define LOCALHOST "127.0.0.1"

#define CAMERAPORT 8080
#define CAMERAIP "192.168.8.10"

#define PI 3.14159265358979323846

servo rotation_servo;
servo swivel_servo;

int init_conn(int port, const char *addr) {

    int fd = create_tcp_socket();
    if (fd < 0) {
        fprintf(stderr, "%s : Failed to create tcp socket\n", addr);
        return -1;
    }

    sockaddr_in server = create_server(KISSPORT, LOCALHOST);

    if (connect(fd, (struct sockaddr *) &server, sizeof(server)) < 0)
    {
        fprintf(stderr, "%s : Failed to connect\n", addr);
        return -1;
    }
    printf("%s : Connection succesful.\n", addr);

    return fd;
}

// Calculate Error (-180 to 180)
float swivel_err(double value) {
    double error = servo_position(&swivel_servo) - value;
    error = fmod(error + 360, 360.0);
    if (error > 180) {
        error -= 360;
    }
    return error;
}

void swivel(double value) {

    double error = 0, prev_error = 0, output = 0;
    clock_t start_time = clock();

    while (1) {

        error = swivel_err(value);

        // Exist Condition
        if (fabs(error) <= 1) {
            servo_set_speed(&swivel_servo, 0);

            start_time = clock();
            while (clock() - start_time < CLOCKS_PER_SEC/10);

            if (fabs(swivel_err(value)) <= 1) break;
        }

        if (clock() - start_time >= CLOCKS_PER_SEC/100)
        {
            //printf("derivative: %f error: %f output %f\n", error - prev_error, error, output);
            if (output * error < 0) {
                output = 0;
                servo_set_speed(&swivel_servo, output);
            }

            if (fabs(error - prev_error) < 1) {
                if (error > 0) output += 0.1;
                if (error < 0) output -= 0.1;
                servo_set_speed(&swivel_servo, output);
            }

            prev_error = error;
            start_time = clock();
        }
    }
}

void self_right() {

    double error = 0, prev_error = 0, output = 0, integral = 0, derivative = 0;
    double x = 0, y = 0, z = 0;
    clock_t start_time = clock();

    while (1) {

        bno055_read_accel_norm(&x, &y, &z);

        error = atan2(y, -z) * 180/PI;

        if (fabs(x) > 0.92 || fabs(error) < 0.1) {
            servo_set_speed(&rotation_servo, 0);

            start_time = clock();
            while (clock() - start_time < CLOCKS_PER_SEC);

            bno055_read_accel_norm(&x, &y, &z);
            if (fabs(x) > 0.92 || fabs(error) < 0.1) break;
        }

        integral += error;
        derivative = error - prev_error;

        output = 3 * error + 0.0001 * integral + 0 * derivative;
        servo_set_speed(&rotation_servo, output);

        prev_error = error;
    }

    servo_set_speed(&rotation_servo, 0);
}

void rotate(double value) {

    self_right();
    servo_zero(&rotation_servo);

    int reverse = value < 0;

    double error = 0, prev_error = 0, output = 0, position = 0;
    clock_t start_time = clock();

    value = fabs(value);
    value /= .316;

    while (1) {

        double position_temp = servo_position(&rotation_servo);
        if (reverse) {
            position_temp = 360 - position_temp;
        }
        if (fabs(position_temp - position) < 180) {
            position = position_temp;
        }

        error = position - value;
        if (reverse) error *= -1;

        if (fabs(error) <= 4) {
            servo_set_speed(&rotation_servo, 0);

            start_time = clock();
            while (clock() - start_time < CLOCKS_PER_SEC/10);

            if (reverse && fabs((360 - servo_position(&rotation_servo)) - value) < 4) break;
            else if (fabs(servo_position(&rotation_servo) - value) < 4) break;
        }

        if (clock() - start_time >= CLOCKS_PER_SEC/100)
        {
            //printf("derivative: %f position %f error: %f output %f\n", error - prev_error, position, error, output);
            if (output * error < 0) {
                output = 0;
                servo_set_speed(&rotation_servo, output);
            }

            if (fabs(error - prev_error) < 4) {
                if (error > 0) output += 0.1;
                if (error < 0) output -= 0.1;
                servo_set_speed(&rotation_servo, output);
            }

            prev_error = error;
            start_time = clock();
        }
    }
}

int main() {

    int camera_socket_fd = init_conn(CAMERAPORT, CAMERAIP);
    int radio_socket_fd = init_conn(KISSPORT, LOCALHOST);

    imu_init();

    swivel_servo.ctrl_pin = "P9_16";
    swivel_servo.prunum = 0;
    init_servo(&swivel_servo);
    servo_zero(&swivel_servo);

    rotation_servo.ctrl_pin = "P8_13";
    rotation_servo.prunum = 1;
    init_servo(&rotation_servo);

    char request[256];
    char response[256];

    strcpy(request, "GET / HTTP/1.1\r\nHost: 192.168.8.10:8000\r\n\r\n");
    write_string(camera_socket_fd, request);
    read_string(camera_socket_fd, response);

    float angle;
    servo_zero(&swivel_servo);
    while (1) {
        /*res = read_buffer(radio_socket_fd, response, 256);
        if (res < 0) {
            //fprintf(stderr, "Failed reading\n");
        }*/
        scanf("%f", &angle);
        swivel(angle);
    }

    close(radio_socket_fd);
    close(camera_socket_fd);
    return 0;
}

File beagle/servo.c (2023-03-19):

#include <stdio.h>
#include <stdint.h>
#include <stdlib.h>
#include <fcntl.h>
#include <unistd.h>
#include <syslog.h>
#include <time.h>
#include <sys/mman.h>

#include "servo.h"
#include "bbio/c_pwm.h"

#define PRU_ADDR   0x4A300000
#define PRU_LEN    0x80000
#define PRU0_DRAM  0x00000
#define PRU1_DRAM  0x02000

#define MAXSPEED 140

#define DCMIN 3
#define DCMAX 95.7

int init_servo(struct servo *servo) {
    BBIO_err err;
    int fd;

    err = pwm_start(servo->ctrl_pin, 7.5, 50, 0);
    if (err != BBIO_OK) {
        syslog(LOG_ERR, "Servo: pwm_start failed");
        return 1;
    }

    fd = open("/dev/mem", O_RDWR | O_SYNC);
    if (fd == -1) {
        syslog(LOG_ERR, "Servo: could not open /dev/mem");
        return 1;
    }

    servo->pru = mmap (0, PRU_LEN, PROT_READ | PROT_WRITE, MAP_SHARED, fd, PRU_ADDR);
    if (servo->pru == MAP_FAILED) {
        syslog(LOG_ERR, "Servo: could not map memory");
        return 1;
    }

    servo->pru_dram = servo->pru + ((servo->prunum ? PRU1_DRAM : PRU0_DRAM) + 0x200)/4;
    close(fd);

    syslog(LOG_DEBUG, "Servo: initialize_servo: OK");
    return 0;
}

double servo_position(struct servo *servo) {
    double high_time = (double)servo->pru_dram[0];
    double total_time = (double)servo->pru_dram[1];

    if (total_time == 0) return 0;

    double duty_cycle = high_time/total_time * 100;
    double angle = (duty_cycle - DCMIN) * 360 / (DCMAX - DCMIN + 1);

    angle = angle - servo->zero;
    angle = (angle < 0) ? 360 + angle : angle;
    angle = (angle > 360) ? 360 : angle;

    return angle;
}

void servo_zero(struct servo *servo) {
    servo->zero = 0.0;
    servo->zero = servo_position(servo);
    syslog(LOG_DEBUG, "Servo: servo_zero: %f\n", servo->zero);
}

void servo_set_speed(struct servo *servo, double speed) {
    double duty_cycle;

    if (speed > MAXSPEED) speed = MAXSPEED;
    if (speed < -MAXSPEED) speed = -MAXSPEED;

    if (speed == 0) {
        duty_cycle = 7.5;
    } else if (speed < 0) {
        duty_cycle = 7.4 + (speed/140.0);
    } else {
        duty_cycle = 7.6 + (speed/140.0);
    }

    pwm_set_duty_cycle(servo->ctrl_pin, duty_cycle);
}

int servo_cleanup(struct servo *servo) {
    int status = 0;

    status = pwm_disable(servo->ctrl_pin);
    if (status != 0) {
        syslog(LOG_ERR, "Servo: servo_cleanup: pwm_disable failed");
        return 1;
    }

    status = munmap(servo->pru, PRU_LEN);
    if (status != 0) {
        syslog(LOG_ERR, "Servo: servo_cleanup: munmap failed");
        return 1;
    }

    syslog(LOG_DEBUG, "Servo: close_servo: OK");
    return 0;
}

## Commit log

2022-12-16 Created main_v1 schematic.
    [main_v1.kicad_pcb, main_v1.kicad_sch]
2022-12-16 Created revision 1.1 of main_v1
    [main_v1.kicad_sch]
2022-12-16 main_v1.2 schematic
    [main_v1.kicad_sch]
2022-12-16 Created v1-3, added kill switch
    [main_v1.kicad_sch]
2022-12-16 Camera schematic v1
    [cam.kicad_pcb, cam.kicad_sch]
2022-12-17 Changed library path, main_v1-4 and cam_v1-1 and Project-OWL block diagrams
    [cam.kicad_pcb, cam.kicad_sch, main.kicad_pcb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]
2022-12-18 Started cape
    [cape.kicad_pcb, cape.kicad_sch]
2022-12-18 first working revision of cape done
    [cape.kicad_pcb, cape.kicad_sch, main.kicad_sch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]
2022-12-19 Finished second revision of cape, basically print-ready
    [cape-B_Cu.gbr, cape-B_Silkscreen.gbr, cape-Edge_Cuts.gbr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]
2022-12-19 Moved cape pdf files to doc
    [cape.kicad_pcb, cape.kicad_sch]
2022-12-29 Preparing to update schematics
2022-12-29 Updated main to 1.5
    [main.kicad_sch]
2022-12-29 Main 1.6, Cam 1.2, added pwr flags and not connected markers to eliminate ERC violations
    [cam.kicad_sch, main.kicad_sch]
2022-12-30 Cape v 1.2
    [L101011MS02Q.step, cape.kicad_pcb, cape.kicad_sch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]
2022-12-30 Cape 1.3, Main 1.7
    [cam.kicad_sch, cape.kicad_pcb, cape.kicad_sch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]
2022-12-30 Genereated step model and moved old doc to Old folder
    [L101011MS02Q.step, cape.kicad_pcb]
2022-12-30 Updated all schematics
    [cam.kicad_sch, cape.kicad_pcb, cape.kicad_sch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]
2023-01-03 Enalrged bno055 footprint pins, made final gerbers
    [cape-B_Cu.gbl, cape-B_Cu.gbr, cape-B_Mask.gbs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]
2023-01-03 Exported gerber to JLC PCB
    [cape-B_Cu.gbl, cape-B_Mask.gbs, cape-B_Paste.gbp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]
2023-01-03 Additional clean commit
    [cape.kicad_pcb]
2023-02-05 Working on post-build payload changes
    [cape.kicad_pcb, cape.kicad_sch]
2023-02-10 Cape v1-5
    [cape.kicad_pcb, cape.kicad_sch]
2023-02-25 Finished schematic v1-5
    [cape.kicad_sch]
2023-02-25 Finished cape v1-5
    [cape.kicad_pcb, cape.kicad_sch]
2023-03-25 rotation and swivel fixed
    [owl.c]
